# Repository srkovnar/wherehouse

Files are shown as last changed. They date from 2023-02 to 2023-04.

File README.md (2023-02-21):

# Wherehouse

Author(s): Sam Kovnar, Sam Hild, Alex Burrowes, Will Oberley

## About this repository

This is the main repository for Team 23, Purdue ECE Senior Design 49022, Spring 2023.

- Subsystem code will be kept in separate folders with the name of the subsystem.
- System code will be found in the folder marked "System".

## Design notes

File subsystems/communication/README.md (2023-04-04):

# Wherehouse: Communication Subsystem

Author(s): Sam Kovnar (Github: srkovnar)

With additional credit to: 
- me-no-dev
- jdunmire

## Table of Contents

1. [TL;DR for TAs and Instructors](#tldr)
2. [About this folder](#about)
3. [Hardware Dependencies](#hardware)
4. [Software Dependencies](#software)
    1. [General](#sw_general)
    2. [ESP8266 Core for Arduino IDE](#esp8266core)
    3. [Additional Firmware Libraries](#fw_libraries)
    4. [KiCad Libraries](#kicad_libraries)
5. [ESP8266 Firmware](#esp_firmware)
    1. [Testing Phase 1](#esp_fw_t1)
    2. [Testing Phase 2](#esp_fw_t2)
    3. [Release Firmware](#esp_fw_release)
6. [Schematics](#schematics)
7. [Documentation](#documentation)

## TL;DR for TAs and Instructors 

The code used for the ESP8266 in the Midterm Demo is at 
`subsystems/communication/esp8266_firmware/esp8266_release/esp8266_release.ino`.
The files contained in `subsystems/communication/esp8266_test_code`
were used for testing and are not being used in the design at this
time. They are being kept solely as documentation.

## About this folder 

This folder (`wherehouse/subsystems/communication`) contains the code
used to test the Communications subsystem of the Wherehouse, Team 23's
Spring 2023 ECE senior design project.

The Communication subsystem is responsible for interactions between the
STM32F0 microcontroller and ESP8266 Wi-Fi module.

## Hardware Dependencies 

The code for ESP8266 devices has been tested on Ai-Thinker's ESP8266 ESP-01 modules.

For flashing and testing the ESP8266 ESP-01 modules, I recommend using
a ESP-01 USB adapter. You can find these from multiple different
vendors. I found mine on eBay.

## Software Dependencies 

### General 

Operating System: Ubuntu 22.04 LTS
- Code functionality on other operating systems can be neither confirmed nor denied

Arduino IDE *(version 2.0.0 or later)*
- This version has been tested on Arduino v2.0.3
- Certain libraries do not work on versions earlier than v2.0.0 for Linux

KiCad *(version 6.0)*
- Certain libraries used for this project are for older versions of
KiCad, but they work fine on more recent versions as well.

### ESP8266 Core for Arduino IDE 

ESP8266 Core for Arduino *(version 3.1.1)*
- ESP8266WiFi.h
- ESP8266HTTPClient.h
- ESP8266WiFiMulti.h

Multiple libraries used in the code contained in this project utilize the ESP8266
Core for Arduino IDE. You must make sure that it is installed.

1.  Open Arduino IDE
2.  Navigate to File > Preferences
3.  Find the textbox labeled "Additional Board Manager URLs"
4.  Insert the following link into the box: http://arduino.esp8266.com/stable/package_esp8266com_index.json, then click "OK".
    - You can have multiple URLs in the box. Just separate them with commas.
5.  Navigate to "Boards Manager"
6.  Search for "esp8266"
7.  Install the board labeled "esp8266 by ESP8266 Community"

### Additional Arduino IDE Libraries 

ESPAsyncWebServer.h (https://github.com/me-no-dev/ESPAsyncWebServer)
- Used by ESP8266 firmware and test code

ESPAsyncTCP.h (https://github.com/me-no-dev/ESPAsyncTCP)
- Required for ESPAsyncWebServer.h to work

To install an Arduino library:
1. Download the library from Github.
    1. Open the Github link to the library in a web browser
    2. Click on the button that says "<> Code". This will bring up a menu.
    3. In the menu that appears, click on "Download ZIP". This will download a .zip folder containing all of the files needed for the library to work.
    4. Keep track of where this .zip file is. It will probably be in your "Downloads" folder.
2. Open Arduino IDE
3. Add the library to your Arduino libraries.
    1. In the toolbar at the top of the Arduino IDE window, click "Sketch" to bring up a drop-down menu.
    2. Hover over "Include Library", then click on "Add .ZIP Library...". A window will appear showing your files.
    3. In the window that just appeared, find the .zip file that you downloaded in step 1. It is most likely in your downloads folder with a name that matches the name of the library (For example, the .zip for ESPAsyncWebServer.h is called `ESPAsyncWebServer-Master.zip`).
    4. Click on the .zip file, then click the "Open" button. This will put the library in your Arduino libraries folder (usually `~/Arduino/libraries` or something similar).
    5. You can delete the .zip file now. You don't need it anymore.
4. The library is now available for you to use, and can be targeted by adding `#include <LIBRARY_NAME.h>` to your code, where "LIBRARY_NAME" is replaced with the name of your library, for example, ESPAsyncWebServer.h.

### KiCad Libraries 

kicad-ESP8266 (https://github.com/jdunmire/kicad-ESP8266)
- Contains schematic and PCB footprints for most commonly used ESP8266 modules, including the ESP-01 which is being used in this project.

To install a KiCad library:
1. Download files from the Github link listed above
2. Open KiCad
3. In the toolbar, go to "Preferences", then click on "Manage Symbol Libraries". A window will appear.
4. In the window that just appeared, click on "Global Libraries" near the top.
5. Click on the Folder icon near the bottom.
6. In the file browser that appears, find the file `kicad-ESP8266/ESP8266.lib`. Click on it, then click "Open".
7. Name it "ESP8266", then click "OK".
8. Repeat steps 3 through 7, but go to "Manage Footprint Libraries" instead of "Manage Symbol Libraries".

## Firmware 

All code for the ESP8266 is written in Arduino format (.ino).
ESP8266 code files begin with 'esp8266_' followed by the name of the
specific project.

Due to the nature of the Arduino IDE, all code files must be kept in
their own folder which shares the project name with the '.ino' file.

### ESP8266 Testing Stage 1: Communications 

**esp8266_ap_test**: Connection test for ESP8266 acting as Access Point

**esp8266_sta_test**: Connection test for ESP8266 acting as Station

The above two code files are a simple test of the ESP8266 WiFi libraries.
The Access Point device should produce serial output that a WiFi access point
was started successfully. Once the Access Point is created, the Station device
should be able to connect and display connection status over Serial lines.

This code was last tested 2023-02-14.

**esp8266_ap_http_test**: HTTP transfer test for ESP8266 acting as Access Point

**esp8266_sta_http_test**: HTTP transfer test for ESP8266 acting as Station

The above two code files are based on a tutorial by RandomNerdTutorials
at https://randomnerdtutorials.com/esp8266-nodemcu-client-server-wi-fi/.
Each should be loaded onto an ESP8266. When both ESP devices are active
(i.e. powered on and running in operation mode), the Station device should
be able to receive data from the Access Point device by requesting from
the /data URL.

This code was last tested 2023-02-16.

### ESP8266 Testing Stage 2: Functionality 

**esp8266_serial_test**: Code for testing Serial UART communication to and from the ESP8266
- Includes a handler for interpreting UART commands
- Serial commands can be sent from the host computer to the ESP8266 via
the Arduino IDE serial monitor
  - Baud rate: 115200
  - In this way, the computer can mimic the behavior of the STM32 which will be
    managing data in the final project
    
**esp8266_sta_router_test**: Test interactions between ESP8266 station and web server via router

### Release Firmware 

**esp8266_release**: Firmware to be used on device
- *This is the code being used in the midterm demo*!

## Schematics 

Schematics for the Communication subsystem are stored in the 
`wherehouse/subsystems/communication/Schematics` directory.

## Documentation 

This folder contains:
- Activity Diagram (`communication_activity_diagram.pdf`), which shows interactions between
microcontroller, wi-fi module, and the web server.
- Block Diagram (`communication_block_diagram.pdf`), which shows the signal connections between
the microcontroller and the wi-fi module.
- PCB Design Review Submission (`communication_pcb_design_review_submission_1.pdf`), which was submitted for the subsystem PCB design review. The schematic used was Version 2.

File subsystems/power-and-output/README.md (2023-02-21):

# Wherehouse: Power and Output Subsystem

This folder contains files relating to the Power & Output Subsystem

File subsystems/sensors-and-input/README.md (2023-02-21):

# Wherehouse: Sensors & Input Subsystem

This folder contains files relating to the Sensors & Input Subsystem.

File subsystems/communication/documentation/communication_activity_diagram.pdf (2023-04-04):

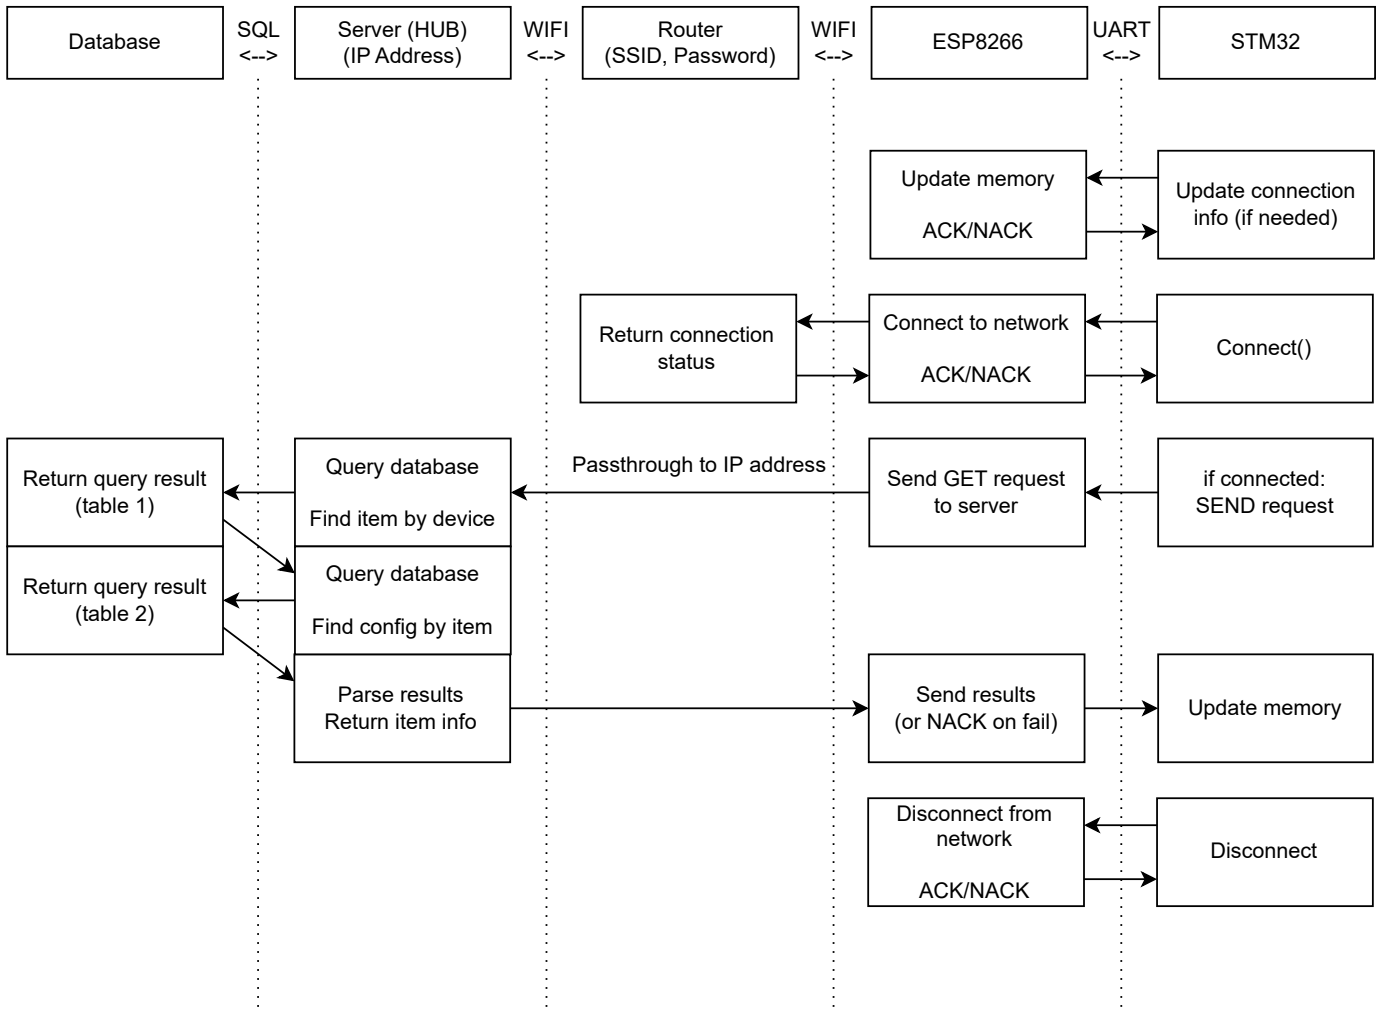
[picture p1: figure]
Connect(); Connect to network; ACK/NACK; Send GET request to server; Update connection info (if needed); Update memory; ESP8266; STM32 Router; (SSID, Password); Server (HUB) (IP Address); if connected: SEND request; Query database; Find item by device; Return query result (table 1); Parse results Return item info; Send results (or NACK on fail); Database; UART; SQL <-->; WIFI <-->; Return connection status; Passthrough to IP address; Find config by item; Return query result (table 2); Disconnect; Disconnect from network

GET ITEM INFO
from server database

Table 1:
Link device ID
to item ID

Table 2:
Link Item ID
to item info
(name, weight, tare)

Table 3:
Link Device ID to
item stock

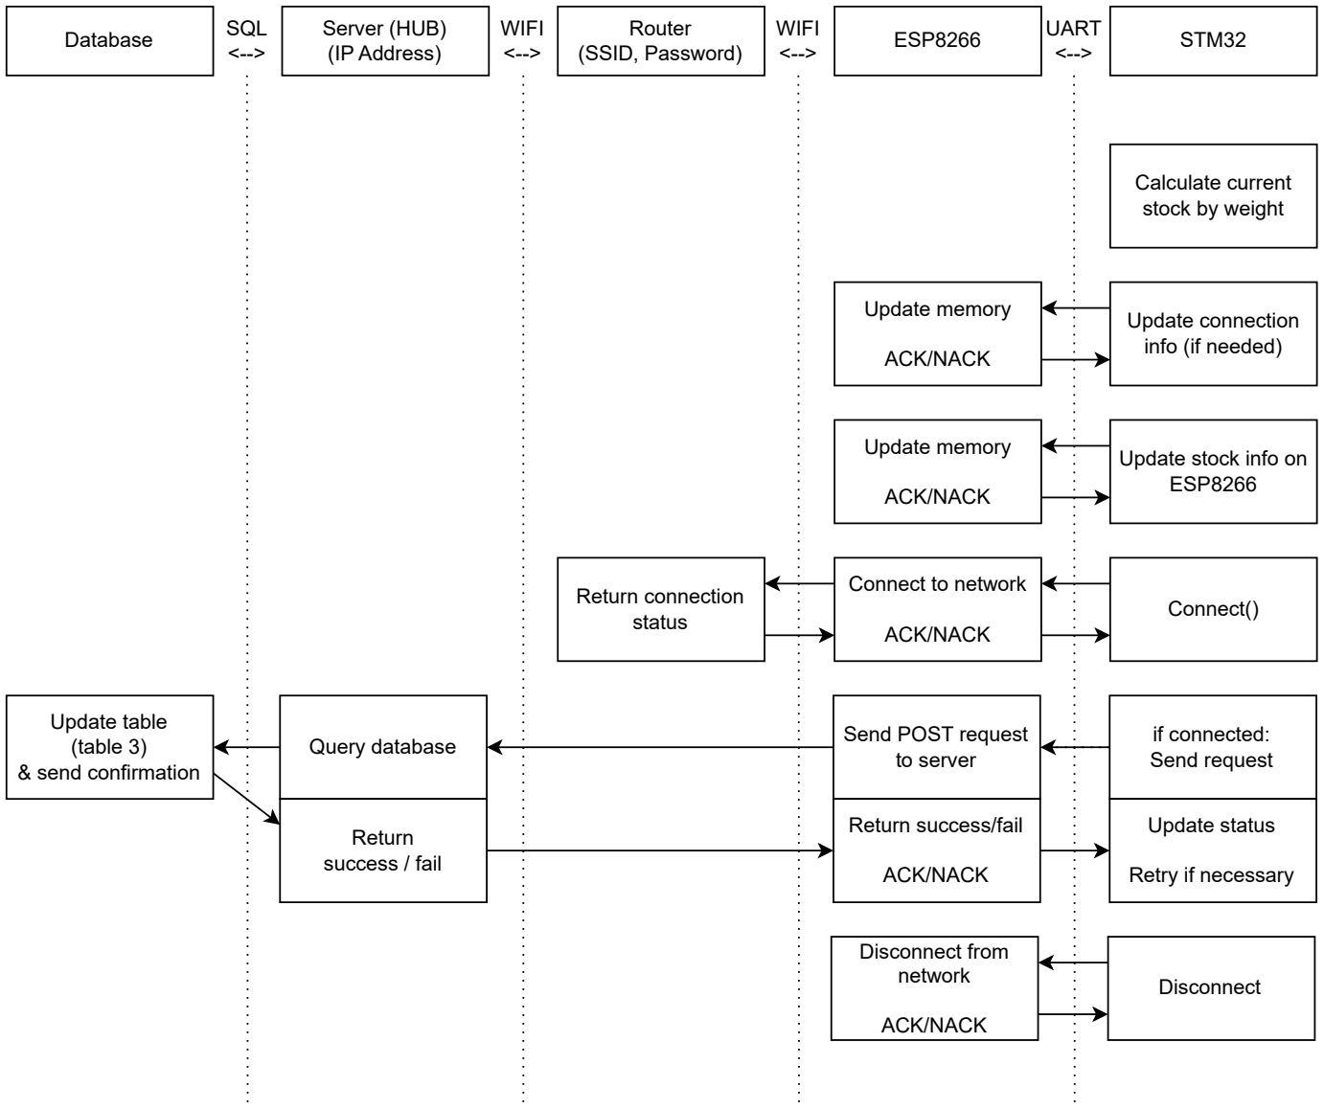
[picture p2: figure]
Connect(); Connect to network; ACK/NACK; Calculate current stock by weight; Update stock info on ESP8266; Update memory; Send POST request to server; Update connection info (if needed); ESP8266; STM32 Router; (SSID, Password); Server (HUB) (IP Address); Query database; Update table (table 3) & send confirmation; Return success / fail; Return success/fail; Database; UART; SQL <-->; WIFI <-->; Return connection status; if connected: Send request; Update status; Retry if necessary; Disconnect; Disconnect from network

UPDATE STOCK

Triggered on timer by
STM32

TABLE 1

Device ID | Item ID
01 | AA

TABLE 2

Table 1:
Link device ID
to item ID

Table 2:
Link Item ID
to item info
(name, weight, tare)

Table 3:
Link Device ID to
item stock
Item ID | Name
AA | shiny rocks

Weight
(per item)
10kg | 5kg

Tare

BB | Widgets | 20kg | 5kg
CC | Soldering
| Irons | 15kg | 5kg

TABLE 3

Device ID | Stock
01 | 11
02 | CC | 02 | 42
03 | DD
DD | Paper | 10kg | 5kg

TABLE 1

Device ID | Item ID
01 | AA
03 | DD
02 | BB

Let's say that
Device 2's
configuration is
updated in the
database
(i.e. we put a new
item on it)

In Table 1, the row
for device 02
(shown in green)
gets updated from
CC to BB.
03 | 28

The next time
Device 02 checks
its configuration,
the server will
respond with the
info for Item BB
(in the blue row).

TABLE 2

Item ID | Name
AA | shiny rocks

Weight
(per item)
10kg | 5kg

Tare

BB | Widgets | 20kg | 5kg
CC | Soldering
| Irons | 15kg | 5kg
DD | Paper | 10kg | 5kg

Even though CC
isn't in stock
anymore, it's still
in Table 2 for the
next time we
stock it.

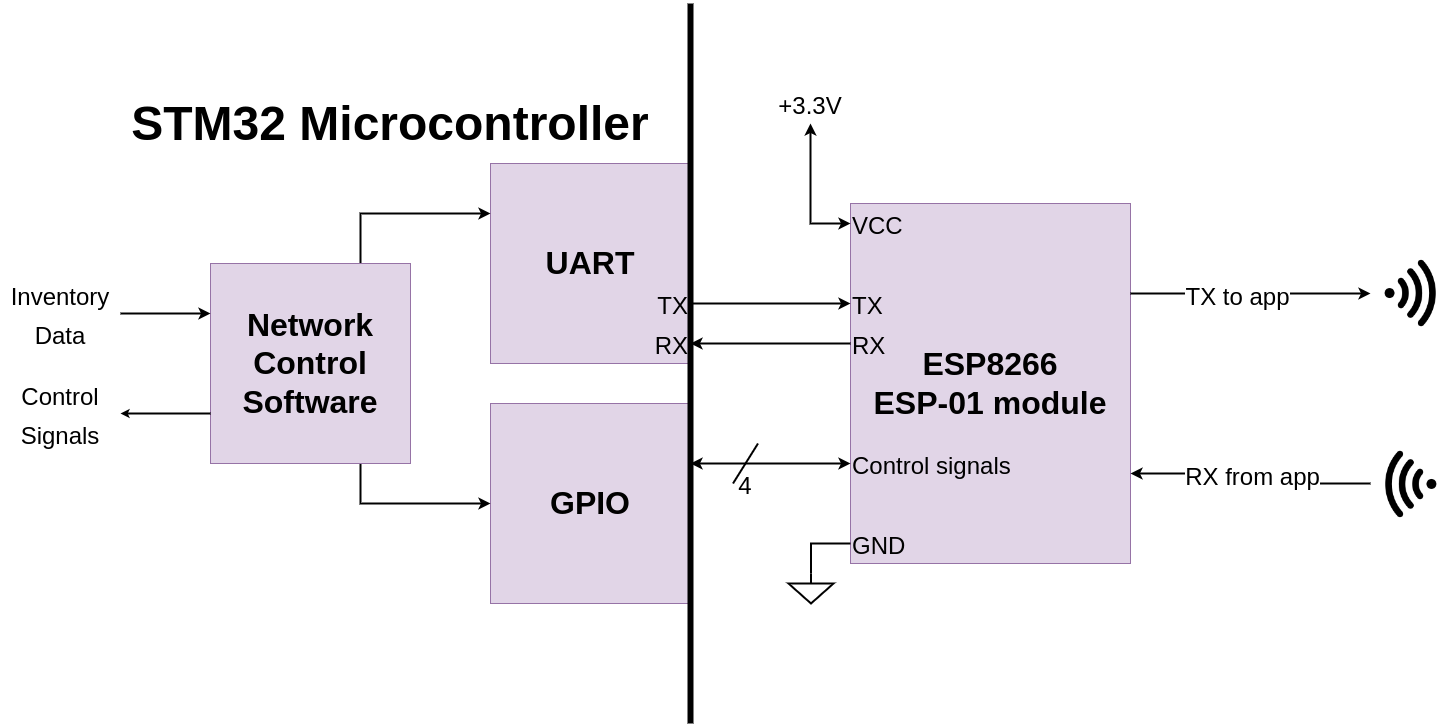
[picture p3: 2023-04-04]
subsystems/communication/documentation/communication_block_diagram.png

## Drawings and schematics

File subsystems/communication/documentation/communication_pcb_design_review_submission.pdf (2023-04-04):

ECE 49022
Team 23: Wherehouse
Communication Subsystem
Sam Kovnar

System Repository (not fully merged yet) https://github.com/srkovnar/wherehouse

- My work is under subsystems/communication
- The firmware I have written for the ESP8266 module is under subsystems/communication/esp8266_firmware

PDF containing my subsystem schematic is attached on the next page of this document.

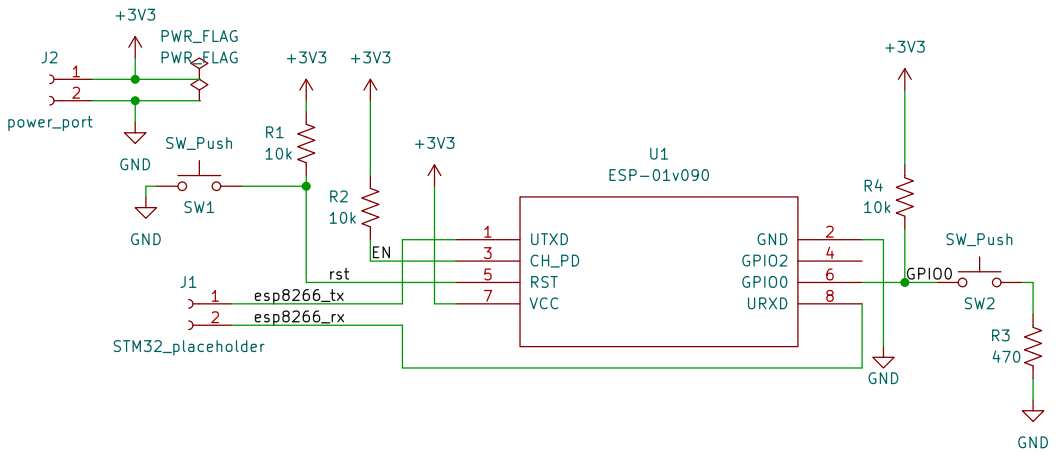
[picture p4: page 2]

File: communication_subsystem_v2.kicad_sch Sheet: / Team 23: Wherehouse ECE 40922 Spring 2023 GND

Id: 1/1 Title: Communication Subsystem Schematic

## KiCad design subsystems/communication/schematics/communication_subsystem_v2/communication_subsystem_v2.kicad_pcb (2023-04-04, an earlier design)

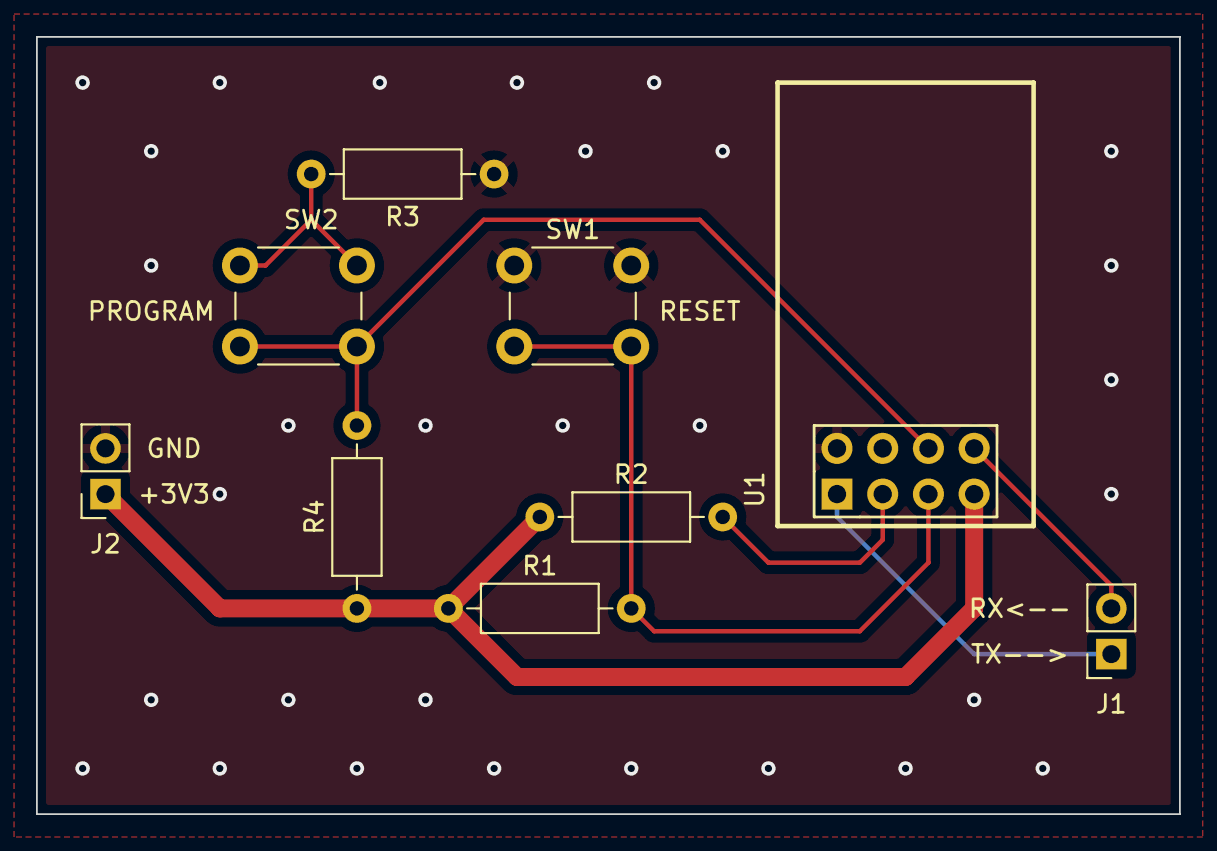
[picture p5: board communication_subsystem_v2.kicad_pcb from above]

Board: 2 copper layers, 63.5 x 43.2 mm, 9 parts (0 on the bottom side), 8 nets.

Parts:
J1: STM32_placeholder; PinSocket_1x02_P2.54mm_Vertical
J2: power_port; PinSocket_1x02_P2.54mm_Vertical
R1, R2, R4: 10k; R_Axial_DIN0207_L6.3mm_D2.5mm_P10.16mm_Horizontal
R3: 470; R_Axial_DIN0207_L6.3mm_D2.5mm_P10.16mm_Horizontal
SW1: RESET; SW_PUSH_6mm_H5mm
SW2: PROGRAM; SW_PUSH_6mm_H5mm
U1: ESP-01v090; ESP-01

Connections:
+3V3: J2.1, R1.1, R2.1, R4.1, U1.7 (VCC)
/EN: R2.2, U1.3 (CH_PD)
/GPIO0: R4.2, SW2.1, U1.6 (GPIO0)
/esp8266_rx: J1.2, U1.8 (URXD)
/esp8266_tx: J1.1, U1.1 (UTXD)
/rst: R1.2, SW1.2, U1.5 (RST)
GND: J2.2, R3.1, SW1.1, U1.2 (GND)
unnamed: R3.2, SW2.2

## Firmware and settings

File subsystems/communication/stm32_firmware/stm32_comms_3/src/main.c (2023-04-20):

#include "stm32f0xx.h"
#include "ff.h"
#include "diskio.h"
#include "fifo.h"
#include "tty.h"
#include <string.h> // for memset()
#include <stdio.h> // for printf()


#define COMM_DELAY 20 // Number of seconds to wait between commands

void advance_fattime(void);
void command_shell(void);

const int ESP_CH_EN = (1 << 0);
const int ESP_RST   = (1 << 1);
const int ESP_GPIO0 = (1 << 2);
const int ESP_GPIO2 = (1 << 3);

const char* run__ping       = "WF+PING!\n";
const char* run__connect    = "WF+CONN!\n";
const char* get__connect    = "WF+CONN?\n";
const char* run__config     = "WF+CNFG!\n";
const char* set__stock      = "WF+STCK=";
const char* run__send       = "WF+SEND!\n";
const char* run__disconnect = "WF+DCON!\n";

int comm_status = 0;
const int CF_TRIGGER    = (1 << 0); // Big trigger, raised once every COMM_DELAY seconds.
const int CF_TRIGGER2   = (1 << 1); // Small trigger, raised every second.

const int CF_WFSTATUS   = (1 << 3); // If HIGH, ESP8266 is in station mode
const int CF_WAITING    = (1 << 4); // If HIGH, a command has been sent and we're waiting for response. (not implemented)
const int RESET_START   = (1 << 5); // UNUSED
const int RESET_END     = (1 << 6); // UNUSED
// ^ This is for saving space on my "status" variable


char global_buffer[100];
int global_buffer_index = 0;

char g_item_name[32];
char g_item_code[32];
char g_unit_weight[32]; // Convert this to int as needed
char g_tare_weight[32]; // Convert this to int as needed

int g_unit_value;
int g_tare_value;

int global_stock = 10;

int comm_counter; // Increments with 1-Hz timer interrupt up to COMM_DELAY






volatile int display_update_flag = 1;
int previous_quantity = 0;
int quantity = 0;






//=====================================================================
// Configure GPIO Pin mode.
// x = Pin number (0, 1, 2, etc.)
// mode = The mode with which to configure the pin
//=====================================================================
void config_pin(GPIO_TypeDef *g, uint8_t x, uint8_t mode)
{
	//INPUT = 00, OUTPUT = 01, ALTERNATE = 10, ANALOG = 11
	g->MODER &= ~(3 << (x * 2));
	g->MODER |= mode << (x * 2);
}

//=====================================================================
// AFR = Alternate Function Register (? I think, it's been a while).
// Need this for enabling UART.
//=====================================================================
void config_afr(GPIO_TypeDef *g, uint8_t x, uint8_t afr)
{
	int addr = x * 4;
	int reg = 0;
	if (x > 8)
	{
		reg = 1;
		addr = (x - 8) * 4;
	}
	g->AFR[reg] &= ~(0xF << addr);
	g->AFR[reg] |= afr << addr;
}



//=====================================================================
// UART setup.
//=====================================================================
void setup_usart5(void)
{
	RCC->AHBENR |= RCC_AHBENR_GPIOCEN; // Enable clock to GPIO port C
	RCC->AHBENR |= RCC_AHBENR_GPIODEN; // Enable clock to GPIO port B

	config_pin(GPIOC, 12, 2); //Set PC12 to AFR2
	config_afr(GPIOC, 12, 2);

	config_pin(GPIOD, 2, 2); //Set PD2 to AFR2
	config_afr(GPIOD, 2, 2);

	RCC->APB1ENR	|= RCC_APB1ENR_USART5EN;
	USART5->CR1 	&= ~USART_CR1_UE;	//Disable before configuring
	USART5->CR1 	&= ~((1<<12) | (1<<28) | USART_CR1_PCE | USART_CR1_OVER8);
	USART5->CR2 	&= ~(USART_CR2_STOP_0 | USART_CR2_STOP_1);
	USART5->BRR  	 = 0x1A1;
	USART5->CR1		|= USART_CR1_TE | USART_CR1_RE;
	USART5->CR1 	|= USART_CR1_UE;	//Enable after configuring

	while((USART5->ISR & USART_ISR_REACK) == 0);
	while((USART5->ISR & USART_ISR_TEACK) == 0);
}


//=====================================================================
// Configure the UART peripheral to raise an interrupt every time that
// a new character arrives.
//=====================================================================
void enable_tty_interrupt(void)
{
	USART5->CR1 |= USART_CR1_RXNEIE;
	NVIC->ISER[0] |= 1 << USART3_8_IRQn;
}


//=====================================================================
// This is the timer that controls WiFi transactions.
//
// Note that TIM6 is generally used with the DAC; at some point,
// it would be good to switch to using a different timer that has a
// more generalized purpose.
//
// Timer calculation example:
// Prescaler = 48000 -> Divide 48MHz system clock by 48000
// Auto-reload register = 500
// 48 MHz * (1/48000) * (1 / 500) = 2 Hz
// -> Interrupt will occur 2 times per second.
// and interrupt handler
// Prescaler can be anywhere from 1 to 65536.
// (I can't find ARR's range in the Family Reference Manual,
// but I know it can be at least 10000.)
//=====================================================================
void setup_tim3(void) {
    // Enable RCC to timer 3
    RCC->APB1ENR |= RCC_APB1ENR_TIM3EN;

    // In Timer 3 Control Register (CR)...
    TIM3->CR1 &= ~TIM_CR1_CEN;
    TIM3->PSC = 47999; // Prescaler = 48000
    TIM3->ARR = 999; // Auto-Reload Register = 1000
    // Should give us a timer that goes off once per second.
    TIM3->DIER |= TIM_DIER_UIE;
    TIM3->CR1 |= TIM_CR1_CEN;

    //Unmask in NVIC_ISER to enable interrupt (FRM page 217)
    NVIC->ISER[0] = 1 << TIM3_IRQn;
}

void TIM3_IRQHandler(void) {
    // Acknowledge interrupt
    TIM3->SR &= ~TIM_SR_UIF;

    // Toggle LED 1
    if (GPIOC->ODR & (1<<7)) {
        GPIOC->ODR &= ~(1<<7);
    }
    else {
        GPIOC->ODR |= (1<<7);
    }

    // Increment secondary counter
    comm_counter = (comm_counter + 1) % COMM_DELAY;// This counts seconds
    if (comm_counter == 0) {
        // Raise flag
        comm_status |= CF_TRIGGER;

        // Toggle LED 2
        if (GPIOC->ODR & (1<<9)) {
            GPIOC->ODR &= ~(1<<9);
        }
        else {
            GPIOC->ODR |= (1<<9);
        }
    }
}


//Step 2.5
int better_putchar(int x)
{
	if (x == '\n')
	{
		while((USART5->ISR & USART_ISR_TXE) == 0);
		USART5->TDR = '\r';
	}
	while((USART5->ISR & USART_ISR_TXE) == 0);
	USART5->TDR = x;
	return x;
}

////Step 2.5
//int better_getchar(void)
//{
//	while((USART5->ISR & USART_ISR_RXNE) == 0);
//	if (USART5->RDR == '\r')
//		return '\n';
//	return USART5->RDR;
//}

//Step 2.7
int interrupt_getchar(void)
{
	USART_TypeDef *u = USART5;
	// Wait for a newline to complete the buffer.


	while(fifo_newline(&input_fifo) == 0) {
	    asm volatile ("wfi");
	}


	// Return a character from the line buffer.
	char ch = fifo_remove(&input_fifo);
	return ch;
}


//=====================================================================
// Pre-defined "weak" method used in printf() and putchar(),
// among other system functions.
//=====================================================================
int __io_putchar(int ch)
{
	//return simple_putchar(ch); //Step 2.4
	return better_putchar(ch); //Step 2.5
}


//=====================================================================
// Pre-defined "weak" method used in fgets() and getchar(),
// among other system functions.
//=====================================================================
int __io_getchar(void)
{
	//return simple_getchar(); //Step 2.4
	//return better_getchar(); //Step 2.5
	//return line_buffer_getchar(); //Step 2.6
	return interrupt_getchar(); //Step 2.7
}


//=====================================================================
// Used in Part 2.7
//
// Interrupt handler for USART5. For details about the interrupt,
// see enable_tty_interrupt(); that's where the interrupt is configured.
// Basically, every time a new character is received over UART,
// this handler is triggered.
//
// (I think, it's been a while since I wrote this code).
//=====================================================================
void USART3_4_5_6_7_8_IRQHandler(void)
{
	USART_TypeDef *u = USART5;
	// If we missed reading some characters, clear the overrun flag.
	if (u->ISR & USART_ISR_ORE)
		u->ICR |= USART_ICR_ORECF;
	int x = u->RDR;
	if (fifo_full(&input_fifo))
		return;
	insert_echo_char(x); // From tty.c
}


// Write your subroutines above.


//=====================================================================
// Wait for either "ACK" or "NACK" from device.
//
// This should really be done in a non-blocking way...
//
// Status:
//    0 = not done yet (or timeout)
//    1 = ACK
//   -1 = NACK
//=====================================================================
int wait_for_response(const char* cmd) {
    int status = 0;
    char cbuf[100];

    int try = 0;
    int attempts = 3;

    printf(cmd);
    while ((status == 0) && (try < attempts)) {
        fgets(cbuf, 99, stdin);
        cbuf[99] = '\0';
        if (strcmp(cbuf, "ACK\n") == 0) {
            status = 1;
        }
        else if (strcmp(cbuf, "NACK\n") == 0) {
            status = -1;
        }
        try++;
    }
    return status;
}

int char_response(const char* cmd, char* store_here) {
    int status = 0;
    char cbuf[100];

    char atest[4];
    char ntest[5];

    int try = 0;
    int attempts = 3;

    // Send command over UART
    printf(cmd);

    // Wait for response
    while((status == 0) && (try < attempts)) {
        fgets(cbuf, 99, stdin); // uses __io_getchar, which uses interrupt_getchar to wait for interrupt on \r
        cbuf[99] = '\0';

        strncpy(atest, cbuf, 3);
        atest[3] = '\0';
        strncpy(ntest, cbuf, 4);
        ntest[4] = '\0';

        if (strcmp(atest, "ACK") == 0) {
            status = 1;
        }
        if (strcmp(ntest, "NACK") == 0) {
            status = -1;
        }

        try++;
    }

    // Move the rest of the string into store_here[]
    if (status == 1) { // Get the value after ACK
        strcpy(store_here, cbuf+3);
    }
    else if (status == -1) {
        strcpy(store_here, cbuf+4);
    }

    // Return 1 if ACK, -1 if NACK, 0 if no response.
    return status;
}


//---------------------------------------------------------------------
// Parse raw text containing "code|item name|unit weight|tare weight"
// into the respective global variables.
//---------------------------------------------------------------------
void parse_configuration(const char* raw_text) {
    int k = 0; // Storage location counter
    int n = 0; // Buffer index

    char delimiter = '|';

    char p_buffer[32];
    p_buffer[31] = '\0'; // Just in case

    char* strplist[] = {g_item_code, g_item_name, g_unit_weight, g_tare_weight};
    // ^ Avoids if-statements
    char ignore_list[] = {':'}; // Not implemented

    //for (int i = 0; i <= strlen(raw_text); i++) {
    for (int i = 1; i <= strlen(raw_text); i++) { //Ignore the first character, it's a colon.
        if (raw_text[i] == delimiter) {
            strcpy(strplist[k], p_buffer);
            n = 0;
            k++;
        }
        // Maybe we should exclude '.'...
        else {
            p_buffer[n] = raw_text[i];
            p_buffer[n+1] = '\0';
            n++;
        }
    }
}


//---------------------------------------------------------------------
// Preliminary function to perform all of the typical wifi interactions
// one after another.
// 1. Send WF+CONN!
// 2. Send WF+CNFG!
// 3. Parse configuration string
// 4. Send WF+STCK=stock
// 5. Send WF+SEND!
// 6. Send WF+DCON!
//
// If at any point in the process we receive a NACK, return a nonzero
// number. This will put the STM32 back in waiting mode, where it just
// repeatedly pings the ESP8266 to see if it's ready and connected
// to WiFi.
//---------------------------------------------------------------------
int wifi_sequence(void) {
    int cmd_response;
    int errors = 0;
    char f_buffer[32];
    f_buffer[31] = '\0'; // Just in case
    char cmd[32];
    cmd[31] = '\0';

    char temp[32];
    temp[31] = '\0';

    int stock = 0;

    cmd_response = char_response(run__connect, f_buffer);
    if (cmd_response != 1) {
        errors++;
    }

    cmd_response = char_response(run__config, f_buffer);
    if (cmd_response != 1) {
        errors++;
    }
    parse_configuration(f_buffer);

    // Stock calculations would happen here

    sprintf(cmd, "%s%ld\n", set__stock, quantity); //Convert int stock to string
    cmd_response = char_response(cmd, f_buffer);
    if (cmd_response != 1) {
        errors++;
    }

    cmd_response = char_response(run__send, f_buffer);
    if (cmd_response != 1) {
        errors++;
    }

    cmd_response = char_response(run__disconnect, f_buffer);
    if (cmd_response != 1) {
        errors++;
    }

    if (errors != 0) {
        return 1;
    }
    else {
        return 0;
    }
}

//---------------------------------------------------------------------
// Send PING command; wait for response. Return 0 if we receive ACK;
// otherwise, return 1 to indicate not ready.
//---------------------------------------------------------------------
int ping_sequence(void) {
    int cmd_response;
    int resp2;
    int errors = 0;

    char f_buffer[32];
    f_buffer[31] = '\0';

    cmd_response = char_response(run__ping, f_buffer);
    if (cmd_response != 1) {
        errors++;
    }

    if (errors != 0) {
        return 1;
    }
    else {
        return 0;
    }
}

//=====================================================================
//                              MERGE
//=====================================================================


void display_ui()
{
    int failed = 0;
    char qty_str[12];

    DISPLAY_clear(0);

    DISPLAY_drawChar(10, 10, '2', 1);
    DISPLAY_drawRect(0, 0, 264, 176, 1);
    DISPLAY_drawRect(5, 5, 254, 166, 0);
    DISPLAY_drawRect(0, 126, 230, 50, 1);
    DISPLAY_drawRect(5, 131, 220, 40, 0);

    DISPLAY_print(9, 133, 1, "Shelf ID: \0");
    DISPLAY_print(9, 80, 1, "Item: 100mH \0");
    DISPLAY_print(9, 40, 1, "Quantity: \0");

    if ( (failed = dtostr(quantity, qty_str, 12) )  == -1 || failed == 0)
    {
        DISPLAY_clear(0);
        DISPLAY_print(4, 40, 1, "ERR: Failed to get string rep\0");
    }
    else
    {
        //DISPLAY_clear(0);
        DISPLAY_print(160,40, 1, qty_str);
        //DISPLAY_print(20,150, 1, qty_str);
        //dtostr(123, qty_str, 12);
        //DISPLAY_print(5,30, 1, qty_str);
        //dtostr(1234, qty_str, 12);
        //DISPLAY_print(5,60, 1, qty_str);
        //dtostr(12345, qty_str, 12);
        //DISPLAY_print(5,90, 1, qty_str);
        //dtostr(123456, qty_str, 12);
        //DISPLAY_print(5,120, 1, qty_str);
        //dtostr(0, qty_str, 12);
        //DISPLAY_print(5,150, 1, qty_str);
    }

    DISPLAY_update();
}


//

void init_tim6()
{
    RCC->APB1ENR |= RCC_APB1ENR_TIM6EN;

    TIM6->CR1 &= ~TIM_CR1_CEN;

    TIM6->PSC = 48000 - 1;
    TIM6->ARR = 1000 - 1;
    TIM6->DIER |= 0x1;

    TIM6->CR1 |= TIM_CR1_CEN;

    NVIC->ISER[0] |= 0x1 << 17;
}

void TIM6_DAC_IRQHandler ()
{
    TIM6->SR &= ~0x1;
    if (quantity != previous_quantity)
    {
        display_update_flag = 1;
    }
}

void init_sensors()
{
    RCC->AHBENR |= RCC_AHBENR_GPIOBEN;
    RCC->AHBENR |= RCC_AHBENR_GPIOCEN;
    GPIOB->MODER |= 0<<(2*14);
    GPIOB->ODR |= 1<<14;
    GPIOB->MODER |= 0<<(2*12);
    GPIOB->ODR |= 1<<12;
    GPIOB->MODER |= 0<<(2*11);
    GPIOB->ODR |= 1<<11;
    GPIOB->MODER |= 0<<(2*10);
    GPIOB->ODR |= 1<<10;
    GPIOB->MODER |= 0<<(2*9);
    GPIOB->ODR |= 1<<9;
    GPIOB->MODER |= 0<<(2*8);
    GPIOB->ODR |= 1<<8;
    GPIOB->MODER &= ~(3<<(2*13));
    GPIOB->MODER |= 1<<(2*13);
    GPIOC->MODER |= 1<<(2*6);
    GPIOB->BRR = GPIO_ODR_13;
    GPIOB->AFR[1] &= ~(GPIO_AFRH_AFRH4 | GPIO_AFRH_AFRH5 | GPIO_AFRH_AFRH7);
    RCC->APB1ENR |= RCC_APB1ENR_SPI2EN;
    SPI2->CR1 |= SPI_CR1_BIDIOE | SPI_CR1_BIDIMODE | SPI_CR1_MSTR | 0x38;   //SPI_CR1_BR;
    SPI2->CR1 &= ~(SPI_CR1_CPOL | SPI_CR1_CPHA);
    SPI2->CR2 = SPI_CR2_DS_3 | SPI_CR2_DS_0 | SPI_CR2_SSOE | SPI_CR2_NSSP;
    SPI2->CR1 |= SPI_CR1_SPE;
}



int main()
{
    // === DISPLAY SETUP ===
    uint32_t value;
    uint32_t fixer;
    uint32_t checker;
    int offset;
    int avg;
    int esp8266_weight = 154;
    int item_weight = 5;
    avg = 0;
    fixer = 0x800000;
    offset = 0;


    init_sensors();
    init_tim6();
    DISPLAY_init();


    // === COMMUNICATION SETUP ===
    // PC0 -> ESP_CH_EN     (STM32 output)
    // PC1 -> ESP_RST       (STM32 output, active low?)
    // PC2 -> ESP_GPIO0     (STM32 output, active low?)
    // PC3 -> ESP_GPIO2     (nothing for now, reserved for future use)

    // The UART pins are being setup by the setup_usart5() function.
    // PC12 -> UART TX (ESP RX)
    // PD2 -> UART RX (ESP TX)

    // Step 1) Enable clocks to GPIO registers in use (I'm only using C for GPIO)
    RCC->AHBENR |= RCC_AHBENR_GPIOCEN;

    // Step 2) Configure GPIO pins as input or output (or analog or alternate function)
    config_pin(GPIOC, 0, 1);
    config_pin(GPIOC, 1, 1);
    config_pin(GPIOC, 2, 1);
    config_pin(GPIOC, 3, 1); // I'm not actually using GPIO2 right now, so I'm gonna
    // link it to an LED to demo that my timer works.
    config_pin(GPIOC, 7, 1); // Dev board LED 2 (orange)
    config_pin(GPIOC, 8, 1); // Dev board LED 3 (green)
    config_pin(GPIOC, 9, 1); // Dev board LED 4 (blue)


    // Now we can set values to be outputted by the GPIO pins.
    GPIOC->ODR &= ~ESP_RST;
    GPIOC->ODR |= ESP_CH_EN;
    GPIOC->ODR |= ESP_GPIO0;
    GPIOC->ODR |= ESP_GPIO2; // Testing using this as CH_EN

    comm_status |= RESET_START; // Signal that reset has been started

    //setup_tim6();
    setup_tim3();

    setup_usart5();

    // Uncomment these when you're asked to...
    setbuf(stdin,0);
    setbuf(stdout,0);
    setbuf(stderr,0);

    enable_tty_interrupt();

    global_buffer[99] = '\0';

    GPIOC->ODR |= ESP_RST;
    comm_status |= RESET_END;


    // === MAIN LOOP TEST ===
    int cstate = 0; //Currently unused
    int result;

    for (;;) {
        // Check if module is in station mode and connected to wifi.
        // If not, ping module on every comm cycle until it's ready.

        if (comm_status & CF_TRIGGER) {
            GPIOC->ODR |= (1<<8);// Turn LED on; comm handling is starting

            if (comm_status & CF_WFSTATUS) {
                result = wifi_sequence();
                if (result != 0) {
                    comm_status &= ~CF_WFSTATUS;
                }
            }
            else {
                result = ping_sequence();
                if (result == 0) {
                    comm_status |= CF_WFSTATUS;
                }
            }

            GPIOC->ODR &= ~(1<<8); // Turn LED off; comm handling is done
            comm_status &= ~CF_TRIGGER; // Lower TRIGGERED flag
        }

        offset = 0;
        checker = (GPIOB->IDR);


        // LOOP 1
        while (GPIOB->IDR & (1<<14)){}
        //for (int x = 0; x < 100; x++){
        value = 0;
        for (int i = 0; i <24; i++){
            wait(5);
            GPIOB->BSRR = GPIO_ODR_13;
            value = value << 1;
            GPIOB->BRR = GPIO_ODR_13;
            if (GPIOB->IDR & (1<<14)){
                value += 1;
            }
            //GPIOB->BSRR = GPIO_ODR_13;
            //GPIOB->BRR = GPIO_ODR_13;
        }


        value = value ^ fixer;
        //    avg += value;
        //}
        //avg = avg / 100;
        //int show = value;
        int balance = (value / 15000) - offset;

        //Buttons
        if ((GPIOB->IDR & (1<<12))){GPIOC->BSRR = GPIO_ODR_6;}
        if (!(GPIOB->IDR & (1<<12))){GPIOC->BRR = GPIO_ODR_6;}
        int holder = GPIOB->IDR & (1<<12);

        // LOOP 2

        while (!(holder & (1<<12))){
            if (!((GPIOB->IDR & (1<<11)))){
                balance += 1;
            }
            if (!((GPIOB->IDR & (1<<11)))){
                balance -= 1;
            }
            if (!((GPIOB->IDR & (1<<9)))){
                balance = 0;
            }
            if (!((GPIOB->IDR & (1<<8)))){
                offset = value / 15000;
            }
            if (!((GPIOB->IDR & (1<<12)))){
                holder = (1<<12);
            }
        }




        //avg = 0;

        quantity =   ((value)/450 - 18480)/item_weight;
        if ( display_update_flag == 1) {
            display_ui();

            display_update_flag = 0;
            previous_quantity = quantity;
        }
    }
}

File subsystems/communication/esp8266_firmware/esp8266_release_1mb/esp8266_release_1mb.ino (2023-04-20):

/*
  Based partly on the Client code from :
  https://randomnerdtutorials.com/esp8266-nodemcu-client-server-wi-fi/

  Also used
  https://forum.arduino.cc/t/concatenate-char/376886/2

  https://reference.arduino.cc/reference/en/language/functions/communication/serial/read/

*/

#include <Arduino.h>
#include <WiFiClient.h>
#include <Hash.h>
#include <EEPROM.h> // Not sure if this board even HAS an eeprom... but it's worth a try.

#include <ESP8266WiFi.h>
#include <ESP8266WiFiMulti.h>
#include <ESP8266HTTPClient.h>

#include <ESPAsyncTCP.h>
#include <ESPAsyncWebServer.h>

#include "communication.h"

// Using EEPROM for storing wifi data so that I don't have to reconfigure it every single time.


#define FW_VERSION "0.2.0" // Readable with WF+VRSN?


#define DOTDELAY 2000 //milliseconds
//#define VERBOSE 1 // Comment out to remove verbose statements

#define CONN_TIMEOUT 10

#define ACK "ACK" //Return this on a success (if no data to return)
#define NACK "NACK" //Return this on a failure
#define HTTP_TAG "http://"

// Error reasons
#define WRONG_MODIFIER    1
#define UNRECOGNIZED_CMD  2
#define FAILED            3

// Decorators
#define GET_ONLY      0
#define SET_ONLY      1
#define RUN_ONLY      2
#define GET_OR_SET    3
#define SET_OR_RUN    4
#define GET_OR_RUN    5
#define ANY_MODIFIER  6

ESP8266WiFiMulti WiFiMulti;

AsyncWebServer server(80);

char local_ssid[MAX_SSID_LENGTH+1] = "Wherehouse Unit ";
char local_password[MAX_PASSWORD_LENGTH+1] = "mypassword";

char ssid[MAX_SSID_LENGTH+1];
char password[MAX_PASSWORD_LENGTH+1];
char server_ip[MAX_IP_LENGTH+1];

const char* server_folder = "/demo"; // The folder where all the php and html files are kept, inside htdocs
const char* data_ext = "/esp-data.php"; // Unused
const char* post_data_ext = "/post-esp-data.php";
const char* get_data_ext = "/get-esp-data.php";

String apiKeyValue = "tpmat5ab3j7f9";
char api_key[32] = "tpmat5ab3j7f9";

char device_id[9] = "0";
//uint32_t device_id = 0;

char stock[MAX_STRING_LENGTH] = "0";
char name[MAX_STRING_LENGTH] = "Widgets"; // Unused


//For connecting to database
const char* dbname = "esp3866_db";
const char* username = "root";
const char* dbpassword = "";

bool switch_to_station; // We're not in station mode, and we should be in access mode.
bool switch_to_access; // We're in access mode, and we should be in station mode.

int status; //Status returned from handling command

// Not all of these are implemented yet... vvv
// Flags (stored in g_status)
const int F__SETUP   = (1 << 0); // If 1, done with setup (unimplemented)
const int F__READY   = (1 << 1); // 0 = still in access point mode. 1 = normal operation (station mode).
const int F__ERROR   = (1 << 2); // Unrecoverable error
const int F__SW2STAT = (1 << 3); // Switch to station mode
const int F__SW2AP   = (1 << 4); // Switch to access point mode
const int F__SERVERUP= (1 << 5); // Raise once server is started

int g_status;


// === COMMAND MATCH STRINGS ===
const char modifier__get = '?';
const char modifier__set = '=';
const char modifier__run = '!';
const char separator = ':';

// Read/Write
const char* cmd__ip     = "WF+IPAD";    // Hub IP Address
const char* cmd__ssid   = "WF+SSID";  // Wi-Fi SSID
const char* cmd__pass   = "WF+PWRD";    // Wi-Fi Password
const char* cmd__id     = "WF+DVID";    // Device ID

const char* cmd__stock  = "WF+STCK"; // Amount of item in stock
const char* cmd__name   = "WF+NAME";  // Name of item

const char* cmd__connect      = "WF+CONN";  // Connect to network
const char* cmd__disconnect   = "WF+DCON";  // Disconnect from network

const char* cmd__send   = "WF+SEND";  //! Send data
const char* cmd__config = "WF+CNFG";   //! Get configuration (item name, weight, tare)

const char* cmd__access  = "WF+APMD"; //! Go back to Access Point mode

// Miscellaneous
const char* cmd__ping   = "WF+PING"; //!
const char* cmd__version= "WF+VRSN"; //?

String data;

unsigned long previous_time;
unsigned long current_time;
const long interval = 500;





// Test for 1MB







// This seems wack, but you can actually program HTML into the C code.
// All you have to do is make sure this gets sent when someone accesses the
// web server. (See the `setup` function for details on how this gets sent).

// Each one of these const char rawliterals is its own HTML page.
// You could probably embed PHP in the same way, although I haven't tried it.
const char index_html[] PROGMEM = R"rawliteral(
  <!DOCTYPE HTML><html>
  <head>
    <meta name="viewport" content="width=device-width, initial-scale=1">
    <link rel="icon" href="data:,">
    <style>
      html {
        font-family: Helvetica;
        display: inline-block;
        margin: 0px auto;
        text-align: center;
      }
      h2 { font-size: 3.0rem; }
      p { font-size: 1.0rem; }
      .button {
        background-color: #195B6A;
        border: none;
        color: white;
        padding: 16px 40px;
        text-decoration: none;
        font-size: 30px;
        marin: 2px;
        cursor: pointer;
      }
      .button2 {
        background-color: #77878A;
      }
    </style>
  </head>
  <body>
    <h1>ESP8266 Web Server</h1>
    <p>
      Current SSID: <span id="ssid">%SSID%</span>
    </p>
    <p>
      Current password: <span id="password">%PASSWORD%</span>
    </p>
    <p>
      Current IP Address: <span id="ip">%IP%</span>
    </p>
    <div>
      <form action="/submitall" method="get">
        <br>
        <label for="fssid">SSID:</label><br>
        <input type="text" id="fssid" name="fssid"><br>
        <label for="fpass">Password:</label><br>
        <input type="text" id="fpass" name="fpass"><br>
        <label for="fipad">Server IP Address:</label><br>
        <input type="text" id="fipad" name="fipad"><br>
        <br><input type="submit" class="button" value="Update Settings"><br>
      </form>
    </div>
    <br><a href="/continue"><button class="button">Done</button><br>
    <br><a href="/scan"><button class="button">Scan for networks</button><br>
  </body>
  </html>
)rawliteral";


String html_replacer(const String& var) {
  // This is passed to the ESP Async Web Server in order
  // to replace %variable% with the actual value stored in memory.
  // The ESPAsyncWebServer.h library accomodates this.
  // For example, %SSID% in the HTML code will be replaced with the value of ssid.

  if (var == "SSID") {
    return String(ssid);
  }
  else if (var == "PASSWORD") {
    return String(password);
  }
  else if (var == "IP") {
    return String(server_ip);
  }
  else {
    return String();
  }
}


int ip_to_int(const char* ip) {
  int final_value = 0;
  int buffer = 0;

  for (int n = 0; n < strlen(ip); n++) {
    if (ip[n] == '.') {
      final_value = (final_value << 8) + buffer;
      buffer = 0;
    }
    else if ((ip[n] >= 48) && (ip[n] <= 57)) {
      buffer = (buffer * 10) + (ip[n] - 48);
    }
  }
  final_value = (final_value << 8) + buffer;

  return final_value;
}
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

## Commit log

2023-02-23 Added Display Drivers
    [New_configuration.cfg]
2023-02-28 reorganizing folders
    [communication_subsystem_v3-B_Cu.gbr, communication_subsystem_v3-B_Mask.gbr, communication_subsystem_v3-B_Paste.gbr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]
2023-02-28 Renaming and added Schematic v2
    [communication_subsystem_v2-B_Cu.gbr, communication_subsystem_v2-B_Mask.gbr, communication_subsystem_v2-B_Paste.gbr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]
2023-02-28 Adding kicad library info
2023-03-02 +Arduino library installation instructions
2023-03-23 Adding stm32 comms workspace
    [lab01 config.cfg, lab10 config.cfg, lab10_debug.cfg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]
2023-04-02 System swap
    [lab01 config.cfg, lab10 config.cfg, lab10_debug.cfg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]
2023-04-02 Fix 1 for release code
    [esp8266_release.ino]
2023-04-03 Fixed DCON and PING, improved flags
    [esp8266_release.ino]
2023-04-04 integrated sensors and dispaly
    [New_configuration (1).cfg]
2023-04-06 Idk y these metadata files keep changing
    [lab01 config.cfg, lab10 config.cfg, lab10_debug.cfg]
2023-04-09 Comm code merged into main code
    [lab01 config.cfg, lab10 config.cfg, lab10_debug.cfg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]
2023-04-09 idk what these do but sure
    [lab01 config.cfg, lab10 config.cfg, lab10_debug.cfg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]
2023-04-20 Buttons working ish
